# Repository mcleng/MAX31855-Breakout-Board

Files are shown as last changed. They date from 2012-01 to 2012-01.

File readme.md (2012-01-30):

MAX31855 Breakout Board
=======================

This work is licensed under a <a rel="license" href="http://creativecommons.org/licenses/by-sa/3.0/">Creative Commons Attribution-ShareAlike 3.0 Unported License</a>.


	
Designed By:

*	Ryan McLaughlin <ryan@ryanjmclaughlin.com>

Summary
-------

This is a simple low-cost breakout for the MAX31855 thermocouple to digital interface from Maxim.  Rather than using a standard SOIC to DIP adapter, you can use this handy breakout to connect a thermocouple and the recommended cap for the IC is already included.  Comes with SMT soldering complete and headers loose.  Also included is a 4050 level shifter for using the chip with 5V systems.

**CAUTION: The MAX31855 is for 3.3V only! If connecting to a 5V system, you must use a level shifter!!**

Tutorial
--------

It is simple to get everything up and running.

1.	Install a header or solder jumper wires to the pin connections
2.	Connect a K-Type [Thermocouple](http://en.wikipedia.org/wiki/Thermocouple Thermocouple) to the terminals
3.	Wire the necessary connections to an Arduino or other micro controller, the bare minimum connections are +V, GND, SCK, SO, CS  **CAUTION: The MAX31855 is for 3.3V only! If connecting to a 5V system, you must use a level shifter!!**
4.	If using an Arduino, load one of the samples from the MAX31855 Arduino Library and you should see temperature information in the serial console. With other micro controllers you can access the chip using a standard SPI interface. See MAX31855 data sheet for more details.

Board Specs
-----------

*	Dimensions: 0.6" x 0.5"
*	Chip: MAX31855
*	Voltage: 3.3V
*	Header: 1x3 (2) 0.1" Pitch

Versions
--------

###Version 1.1

Primary change with this version was to remove the small SMT header with  more standard 3.5mm screw terminal.

* Updated the layout and routing for the new terminals
* Kept the existing DIP layout
* Overall footprint reduced to 0.6" x 0.5"

####Board Specs

*	Dimensions: 0.6" x 0.5"
*	Chip: MAX31855
*	Header: 1x3 (2) 0.1" Pitch

###Version 1.0

Initial version of the board with a small SMT header. <small>Licensed under OSHW</small>

* 	Initial release under Eagle 6.1 on Github
*	DIP format for easy breadboarding
*	Recommended cap is included on the breakout
*	Production dates: 05-2011

####Board Specs
*	Dimensions: 0.6" x 0.6"
*	Chip: MAX31855
*	Header: 1x3 (2) 0.1" Pitch

Purchase
--------

[store.ryanjmclaughlin.com](http://store.ryanjmclaughlin.com).

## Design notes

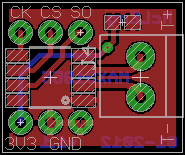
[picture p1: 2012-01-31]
MAX31855-Breakout-Board.png

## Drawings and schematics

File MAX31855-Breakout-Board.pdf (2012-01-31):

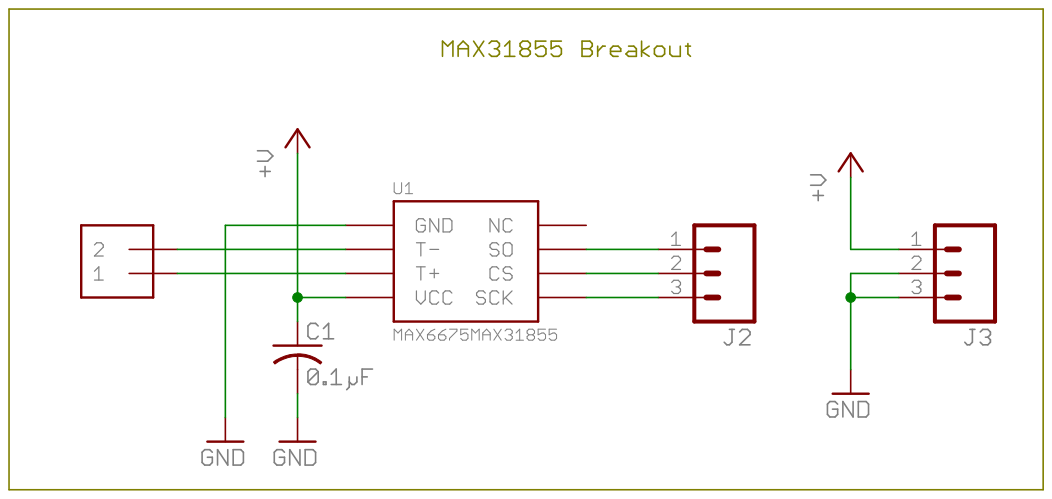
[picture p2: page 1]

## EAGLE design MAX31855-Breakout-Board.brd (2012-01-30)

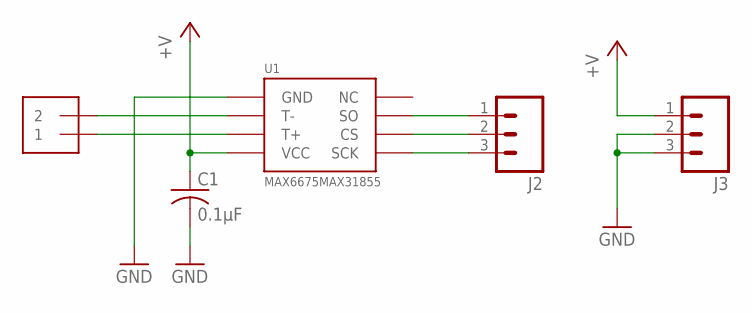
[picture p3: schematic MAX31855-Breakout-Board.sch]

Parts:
C1: 0.1µF; C0603
J2, J3: M031X03_NO_SILK; 1X03_NO_SILK
J4: 1X2-3.5MM
U1: MAX6675MAX31855; SOIC-8

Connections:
+5V: C1.1, J3.1, U1.VCC
CS: J2.2, U1.CS
GND: C1.2, J3.2, J3.3, U1.GND
SCK: J2.3, U1.SCK
SO: J2.1, U1.SO
T+: J4.1, U1.T+
T-: J4.2, U1.T-

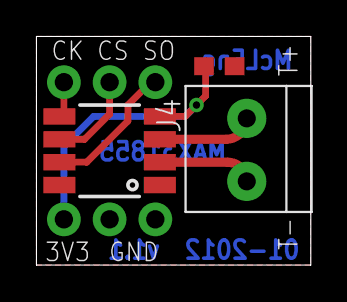
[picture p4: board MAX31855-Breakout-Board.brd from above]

Board: 2 copper layers, 15.2 x 12.7 mm, 5 parts (0 on the bottom side), 7 nets.

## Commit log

2012-01-30 Initial release on Github, v1.0
    [MAX31855-Breakout-Board.brd, MAX31855-Breakout-Board.sch]
2012-01-30 Updated to use screw terminal header and updated for v1.1 and 01-2012 production
    [MAX31855-Breakout-Board.brd, MAX31855-Breakout-Board.sch]
2012-01-31 Added schematic and board images/pdf

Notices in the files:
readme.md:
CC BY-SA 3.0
